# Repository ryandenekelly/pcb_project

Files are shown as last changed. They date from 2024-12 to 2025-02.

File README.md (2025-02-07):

# STM32 PCB Project
**Very much a work in progress**

PCB prototype project using KiCad and based on ST32F411RET7. 
The goal is to utilise the SSD1306 or ST7735 LCD displays and RFM69 radio to make a sensor sever / controller.

## Schematic
### MCU

Circuitry to power microcontroller and its nesessary parts.

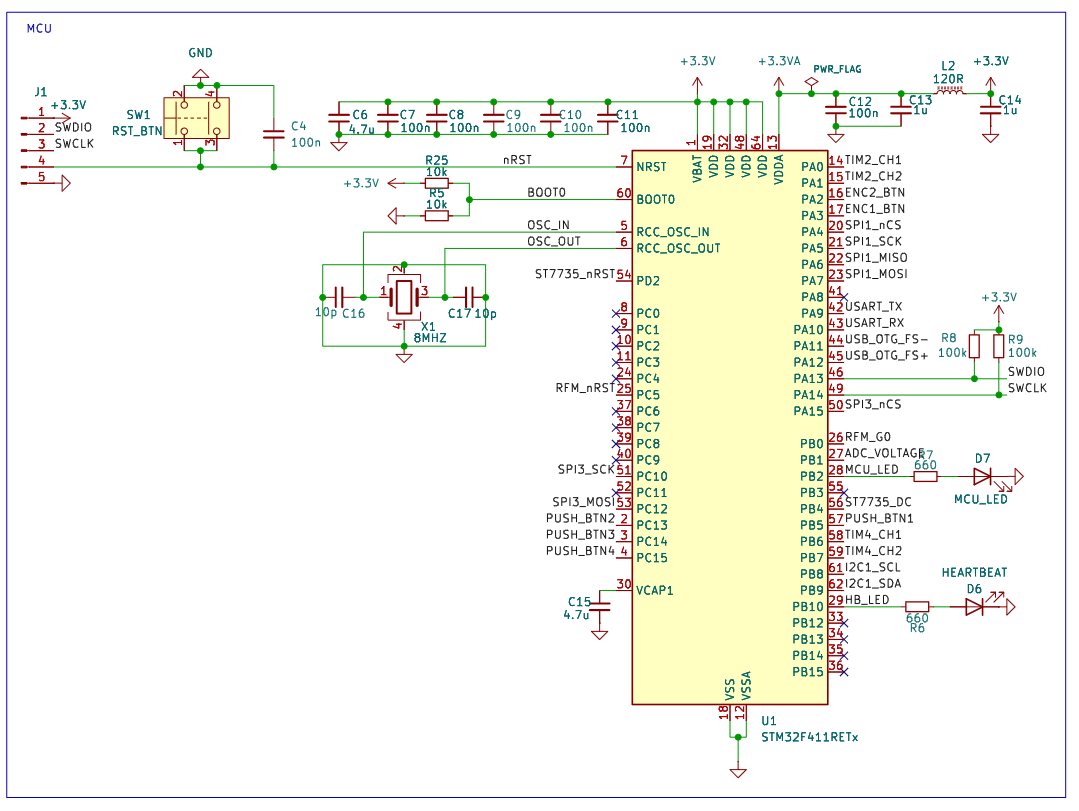
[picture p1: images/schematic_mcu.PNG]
MCU section of the schematic


### Power

USB-C/Battery power and regulator.

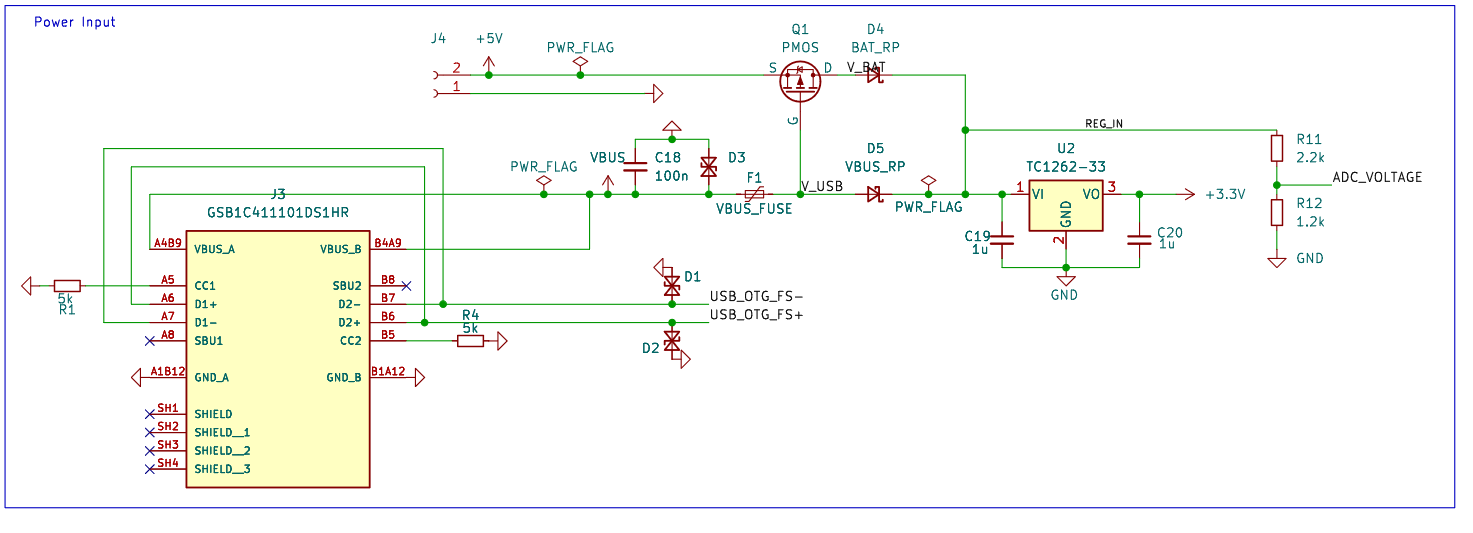
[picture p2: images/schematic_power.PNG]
Power section of the schematic

### UART
USB-B UART input.
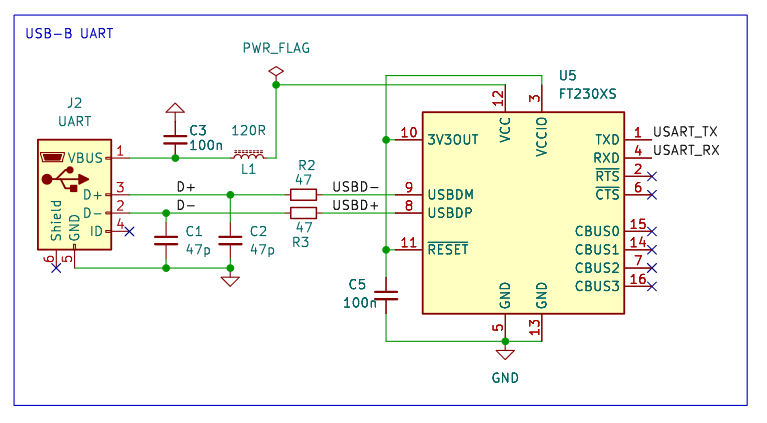
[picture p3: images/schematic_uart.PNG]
UART section of the schematic

### Radio and Display
Headers for RFM69 radio and LCD displays
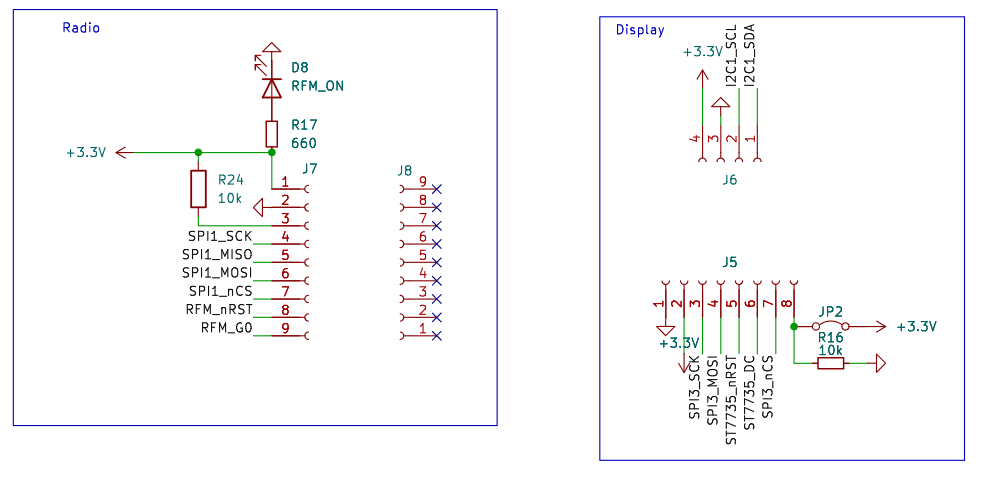
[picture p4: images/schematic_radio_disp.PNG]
Radio and display section of the schematic

### Input
Push button and encoder input with filtering.
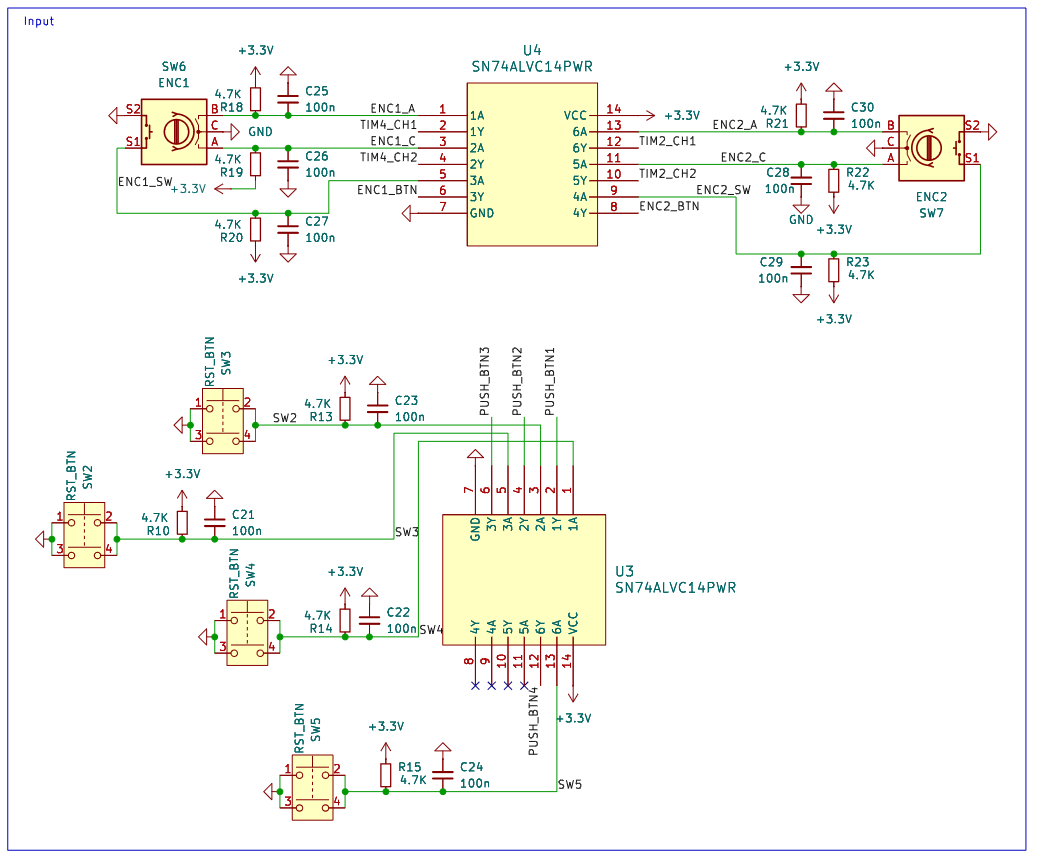
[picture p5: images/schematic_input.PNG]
Input section of the schematic


## PCB

First version of PCB

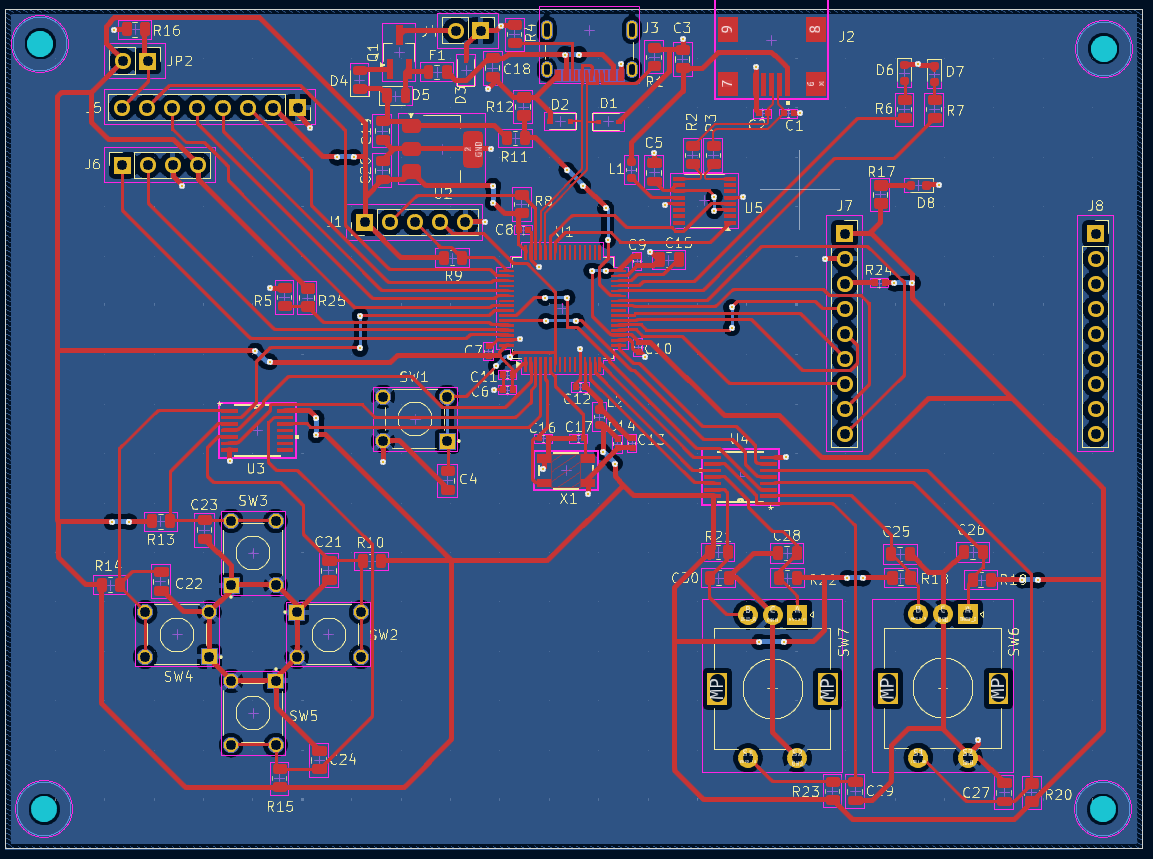
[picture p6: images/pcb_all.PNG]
Full PCB


### Top Layer

Top layer containing the signals and power.

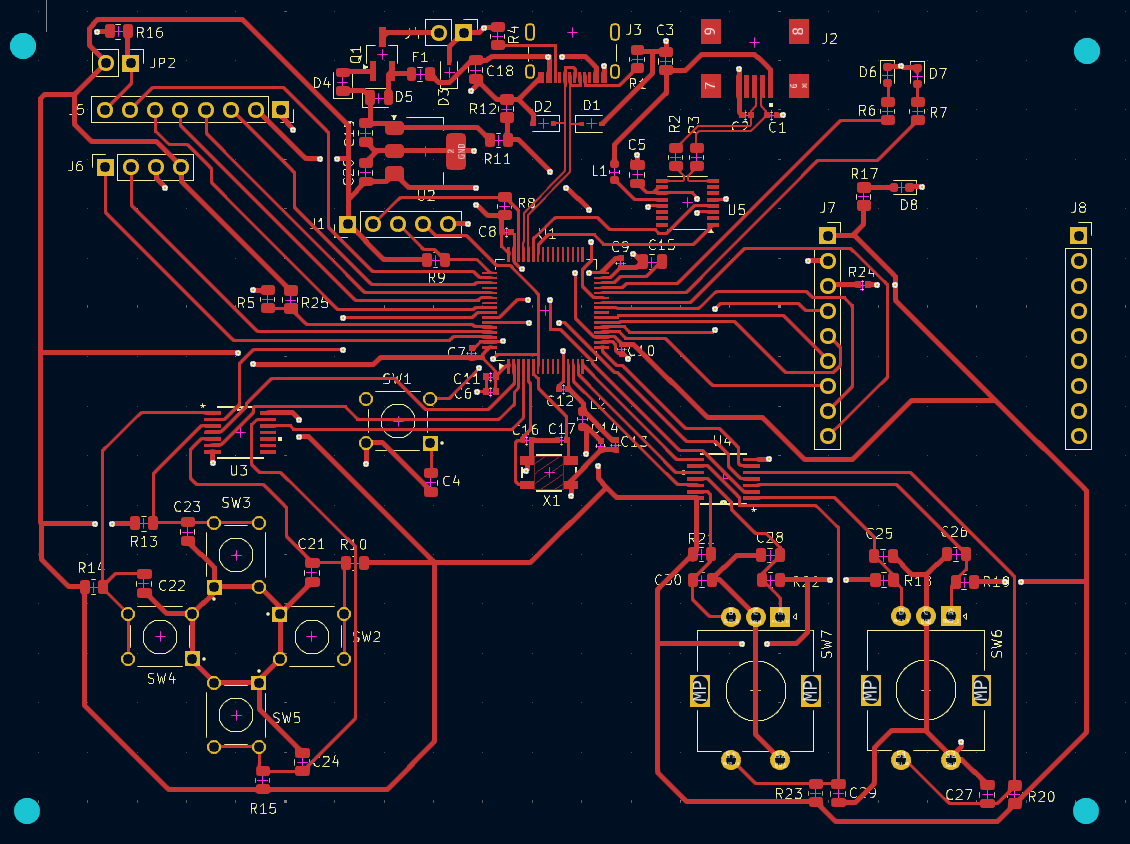
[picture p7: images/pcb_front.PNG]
Just the top layer of the PCB


### Bottom Layer

Bottom layer containing mostly the GND plane, with some signals from vias.

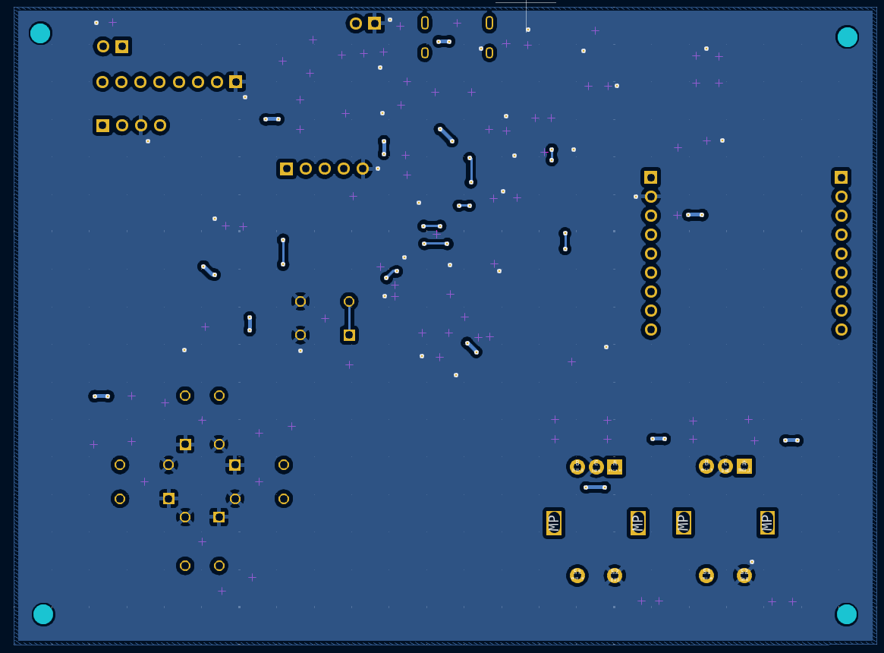
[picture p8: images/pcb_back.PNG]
Just the bottom layer of PCB


### Future Improvement

Currently in the proccess of assembling pcb. The wrong size capacitors were ordered for C13 and C14, but were assembled with some reworking.
May need re-design on crystal oscilator to use a part that is more easily hand soldered. Boot and reset nets may need reworking.

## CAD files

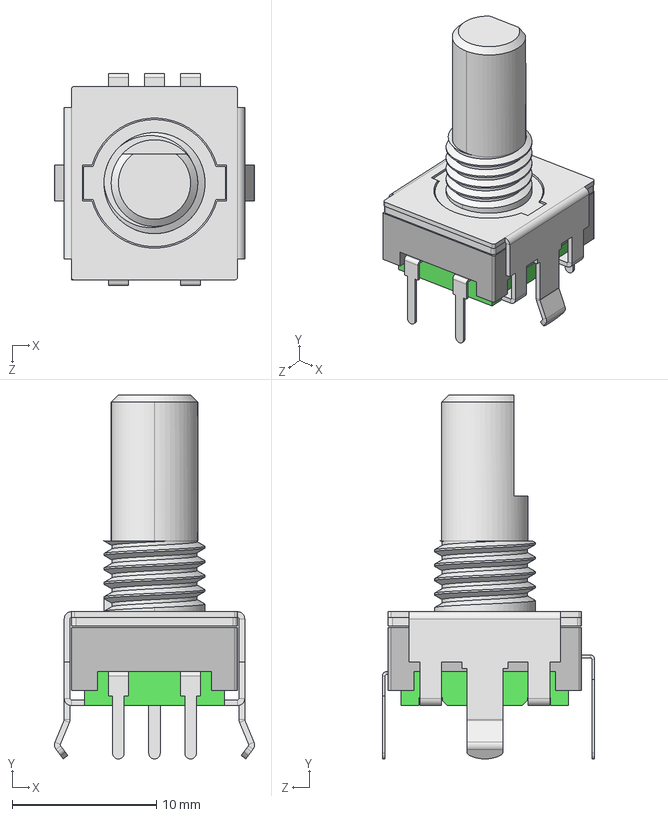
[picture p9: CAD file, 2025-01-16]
project_library/PEC11R-4215F-S0024.step
13.9 x 25.2 x 14.7 mm

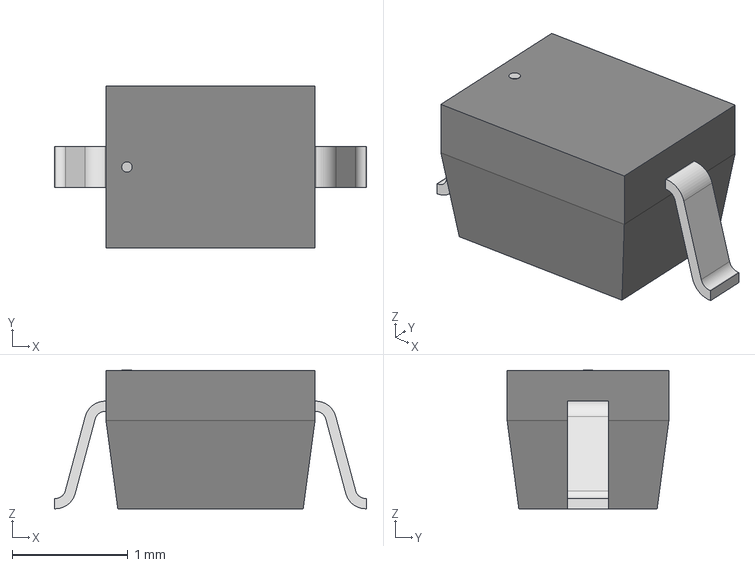
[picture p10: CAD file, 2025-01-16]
project_library/SOD323-L_DIO.step
2.69 x 1.40 x 1.20 mm

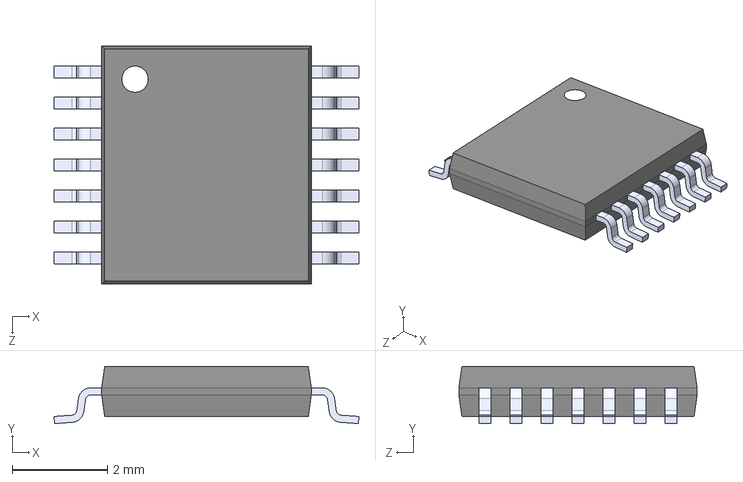
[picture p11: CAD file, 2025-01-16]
project_library/SN74ALVC14PWR.step
6.40 x 1.20 x 5.00 mm

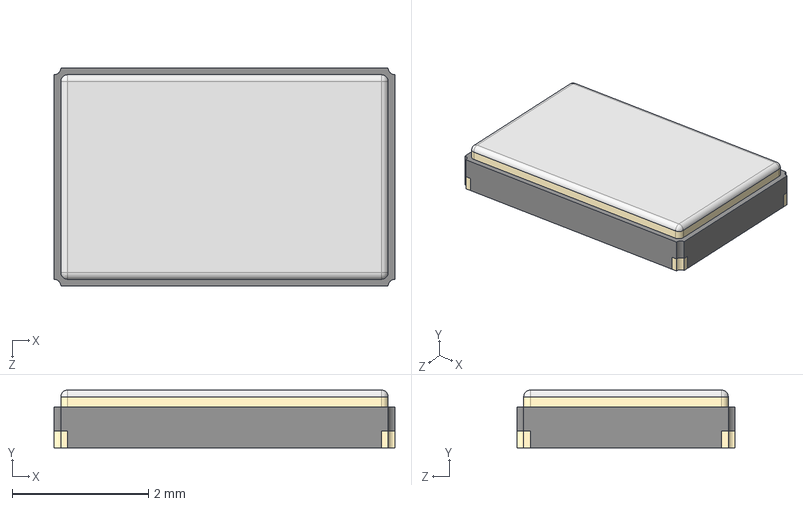
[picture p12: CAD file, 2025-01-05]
project_library/ECS-80-10-30B-CKM-TR.step
5.00 x 0.85 x 3.20 mm

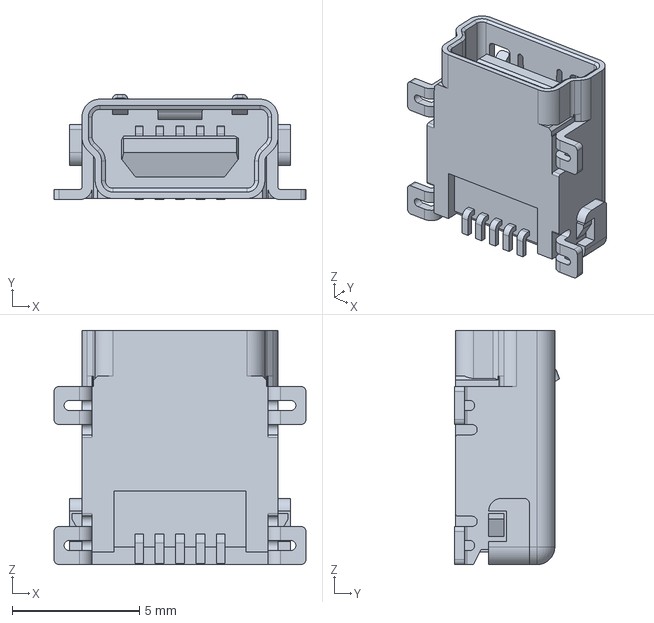
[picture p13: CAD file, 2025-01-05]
project_library/c-1-1734035-2-f-3d.stp
9.90 x 4.14 x 9.20 mm

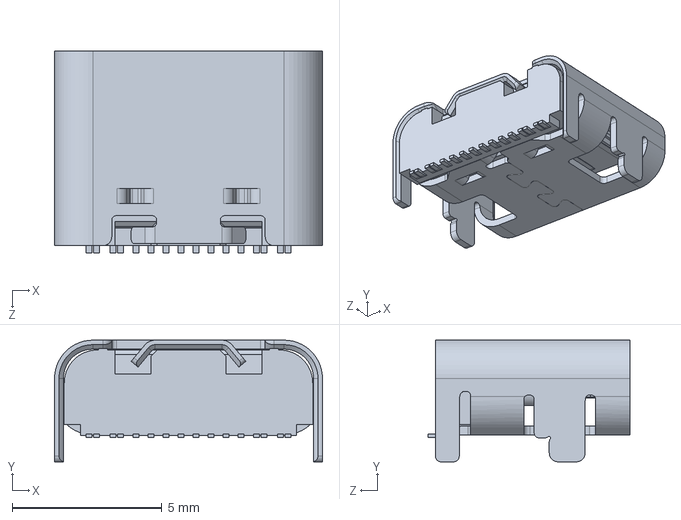
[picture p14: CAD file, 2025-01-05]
project_library/GSB1C411101DS1HR.step
8.94 x 4.06 x 6.75 mm

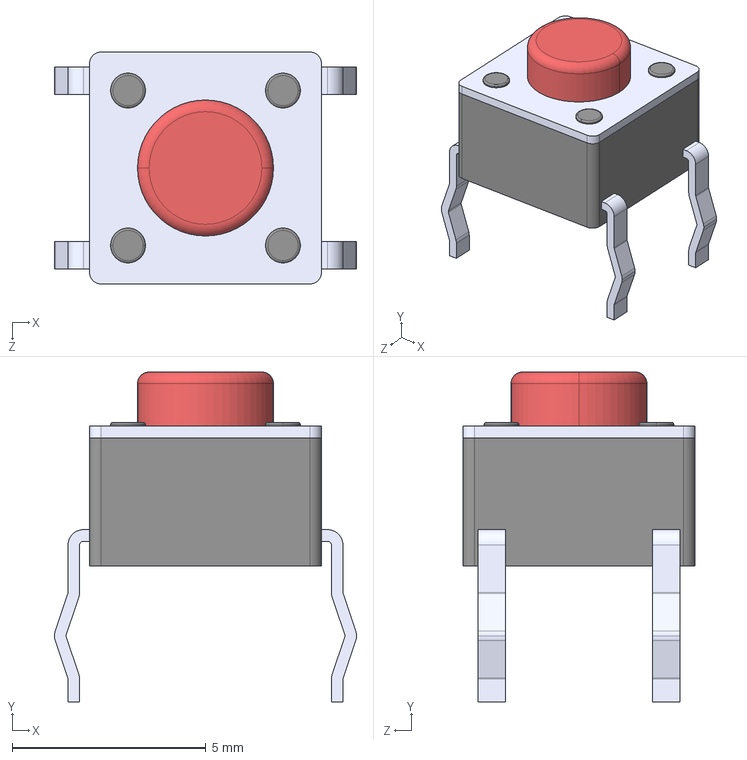
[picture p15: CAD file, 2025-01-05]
project_library/1825910-6.step
7.80 x 8.52 x 5.99 mm

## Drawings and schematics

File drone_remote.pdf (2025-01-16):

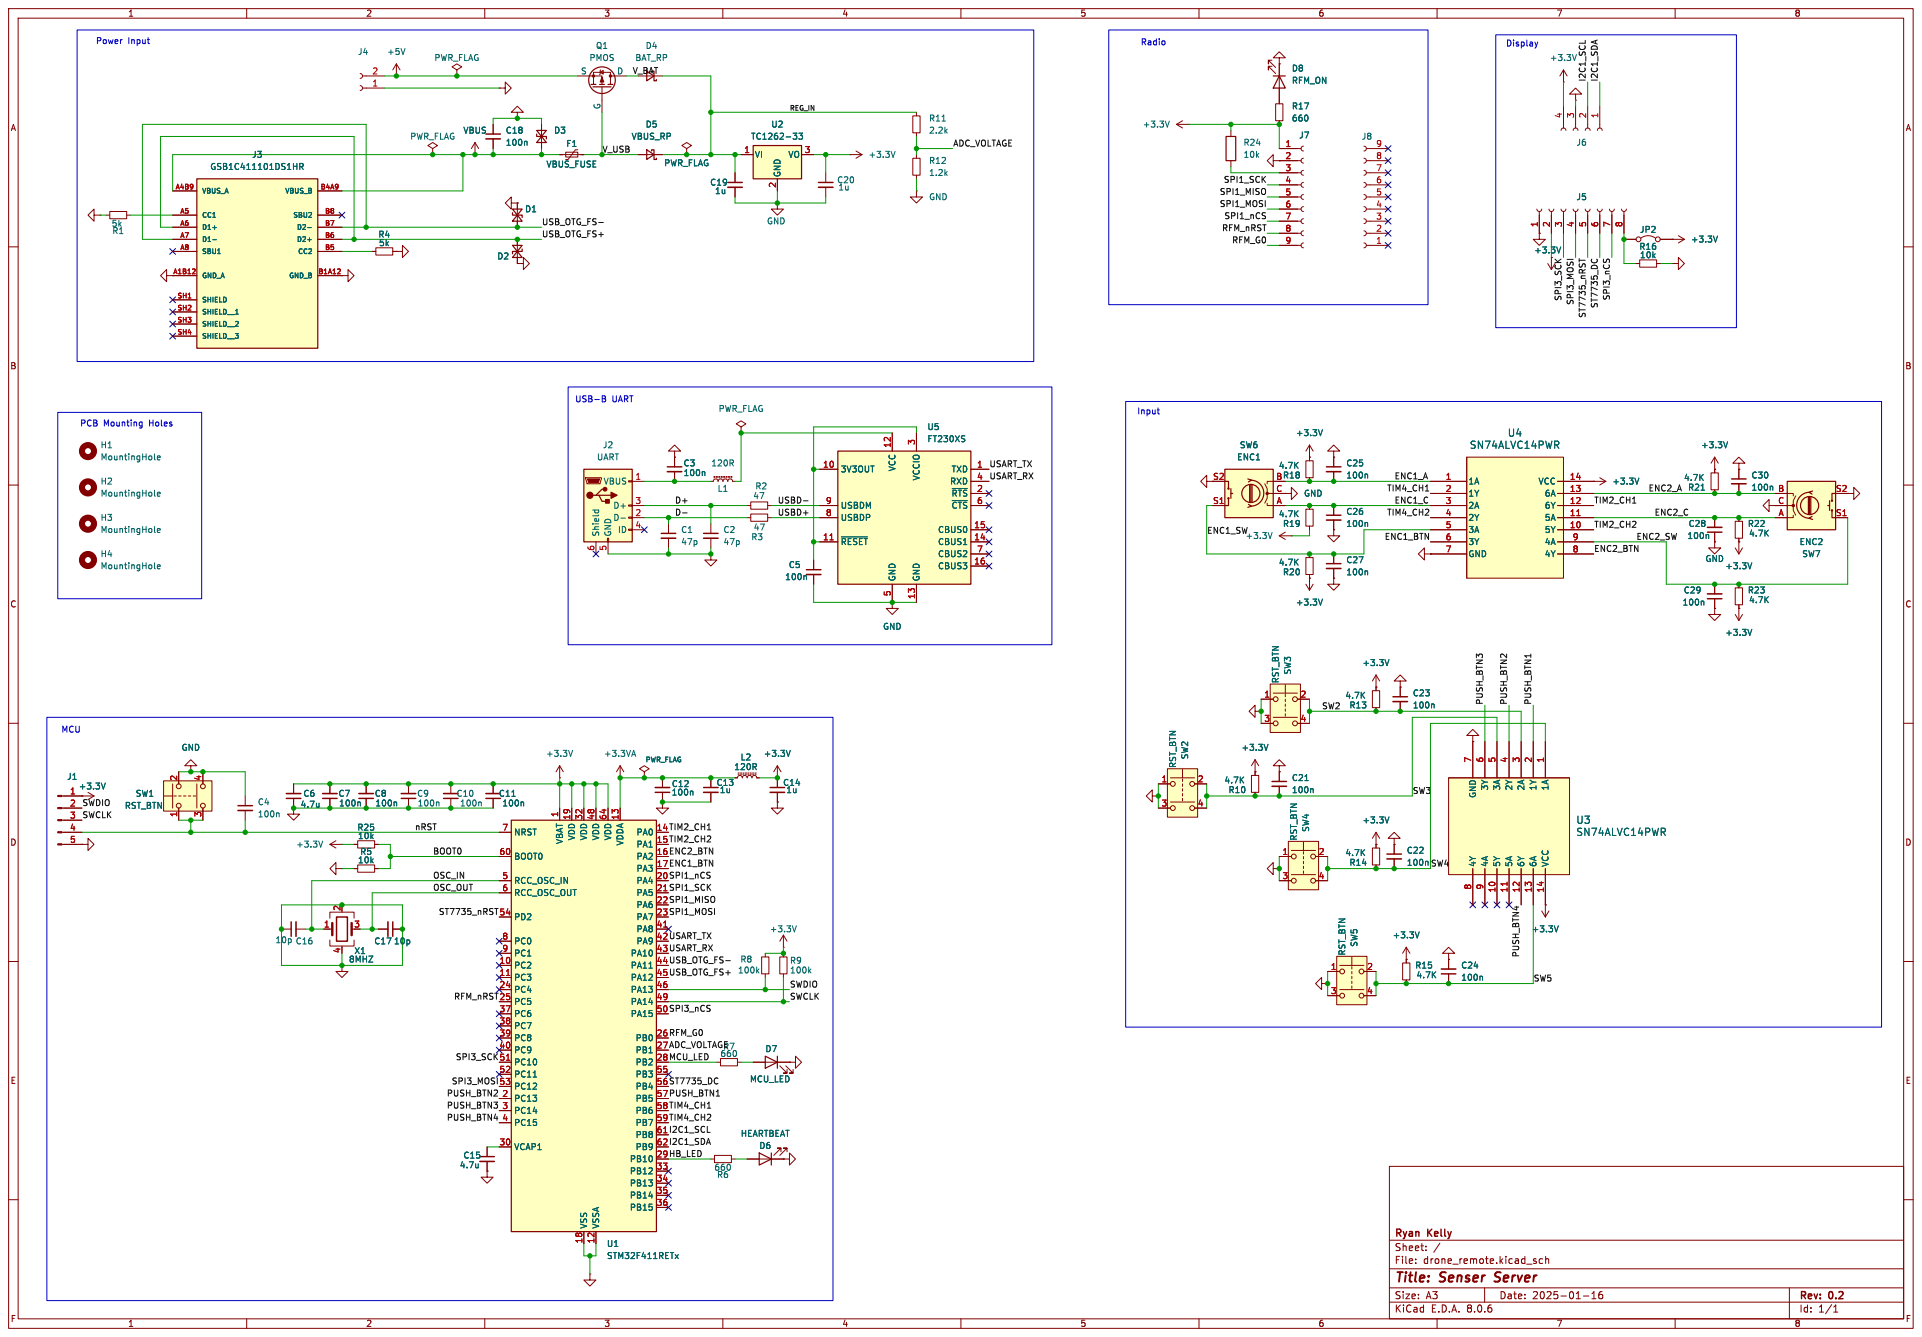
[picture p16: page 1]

5 ~{CTS}6 CBUS2 7 USBDP 8 USBDM 9 GND

1 PC2 10 PC3 11 VSSA 12 VDDA 13 PA0 14 PA1 15 PA2 16 PA3 17 VSS 18 VDD 19 PC13 2 PA4 20 PA5 21 PA6 22 PA7 23 PC4 24 PC5 25 PB0 26 PB1 27 PB2 28 PB10 29 PC14 3 VCAP1 30 VDD 32 PB12 33 PB13 34 PB14 35 PB15 36 PC6 37 PC7 38 PC8 39 PC15 4 PC9 40 PA8 41 PA9 42 PA10 43 PA11 44 PA12 45 PA13 46 VDD 48 PA14 49 RCC_OSC_IN 5 PA15 50 PC10 51 PC11 52 PC12 53 PD2 54 PB3 55 PB4 56 PB5 57 PB6 58 PB7 59 RCC_OSC_OUT 6 BOOT0 60 PB8 61 PB9 62 VDD 64 NRST 7 PC0 8 PC1 9 C15

1 PC2 10 PC3 11 VSSA 12 VDDA 13 PA0 14 PA1 15 PA2 16 PA3 17 VSS 18 VDD 19 PC13 2 PA4 20 PA5 21 PA6 22 PA7 23 PC4 24 PC5 25 PB0 26 PB1 27 PB2 28 PB10 29 PC14 3 VCAP1 30 VDD 32 PB12 33 PB13 34 PB14 35 PB15 36 PC6 37 PC7 38 PC8 39 PC15 4 PC9 40 PA8 41 PA9 42 PA10 43 PA11 44 PA12 45 PA13 46 VDD 48 PA14 49 RCC_OSC_IN 5 PA15 50 PC10 51 PC11 52 PC12 53 PD2 54 PB3 55 PB4 56 PB5 57 PB6 58 PB7 59 RCC_OSC_OUT 6 BOOT0 60 PB8 61 PB9 62 VDD 64 NRST 7 PC0 8 PC1 9 U1STM32F411RETx

Id: 1/1 Title: Senser Server File: drone_remote.kicad_sch Sheet: / Ryan Kelly

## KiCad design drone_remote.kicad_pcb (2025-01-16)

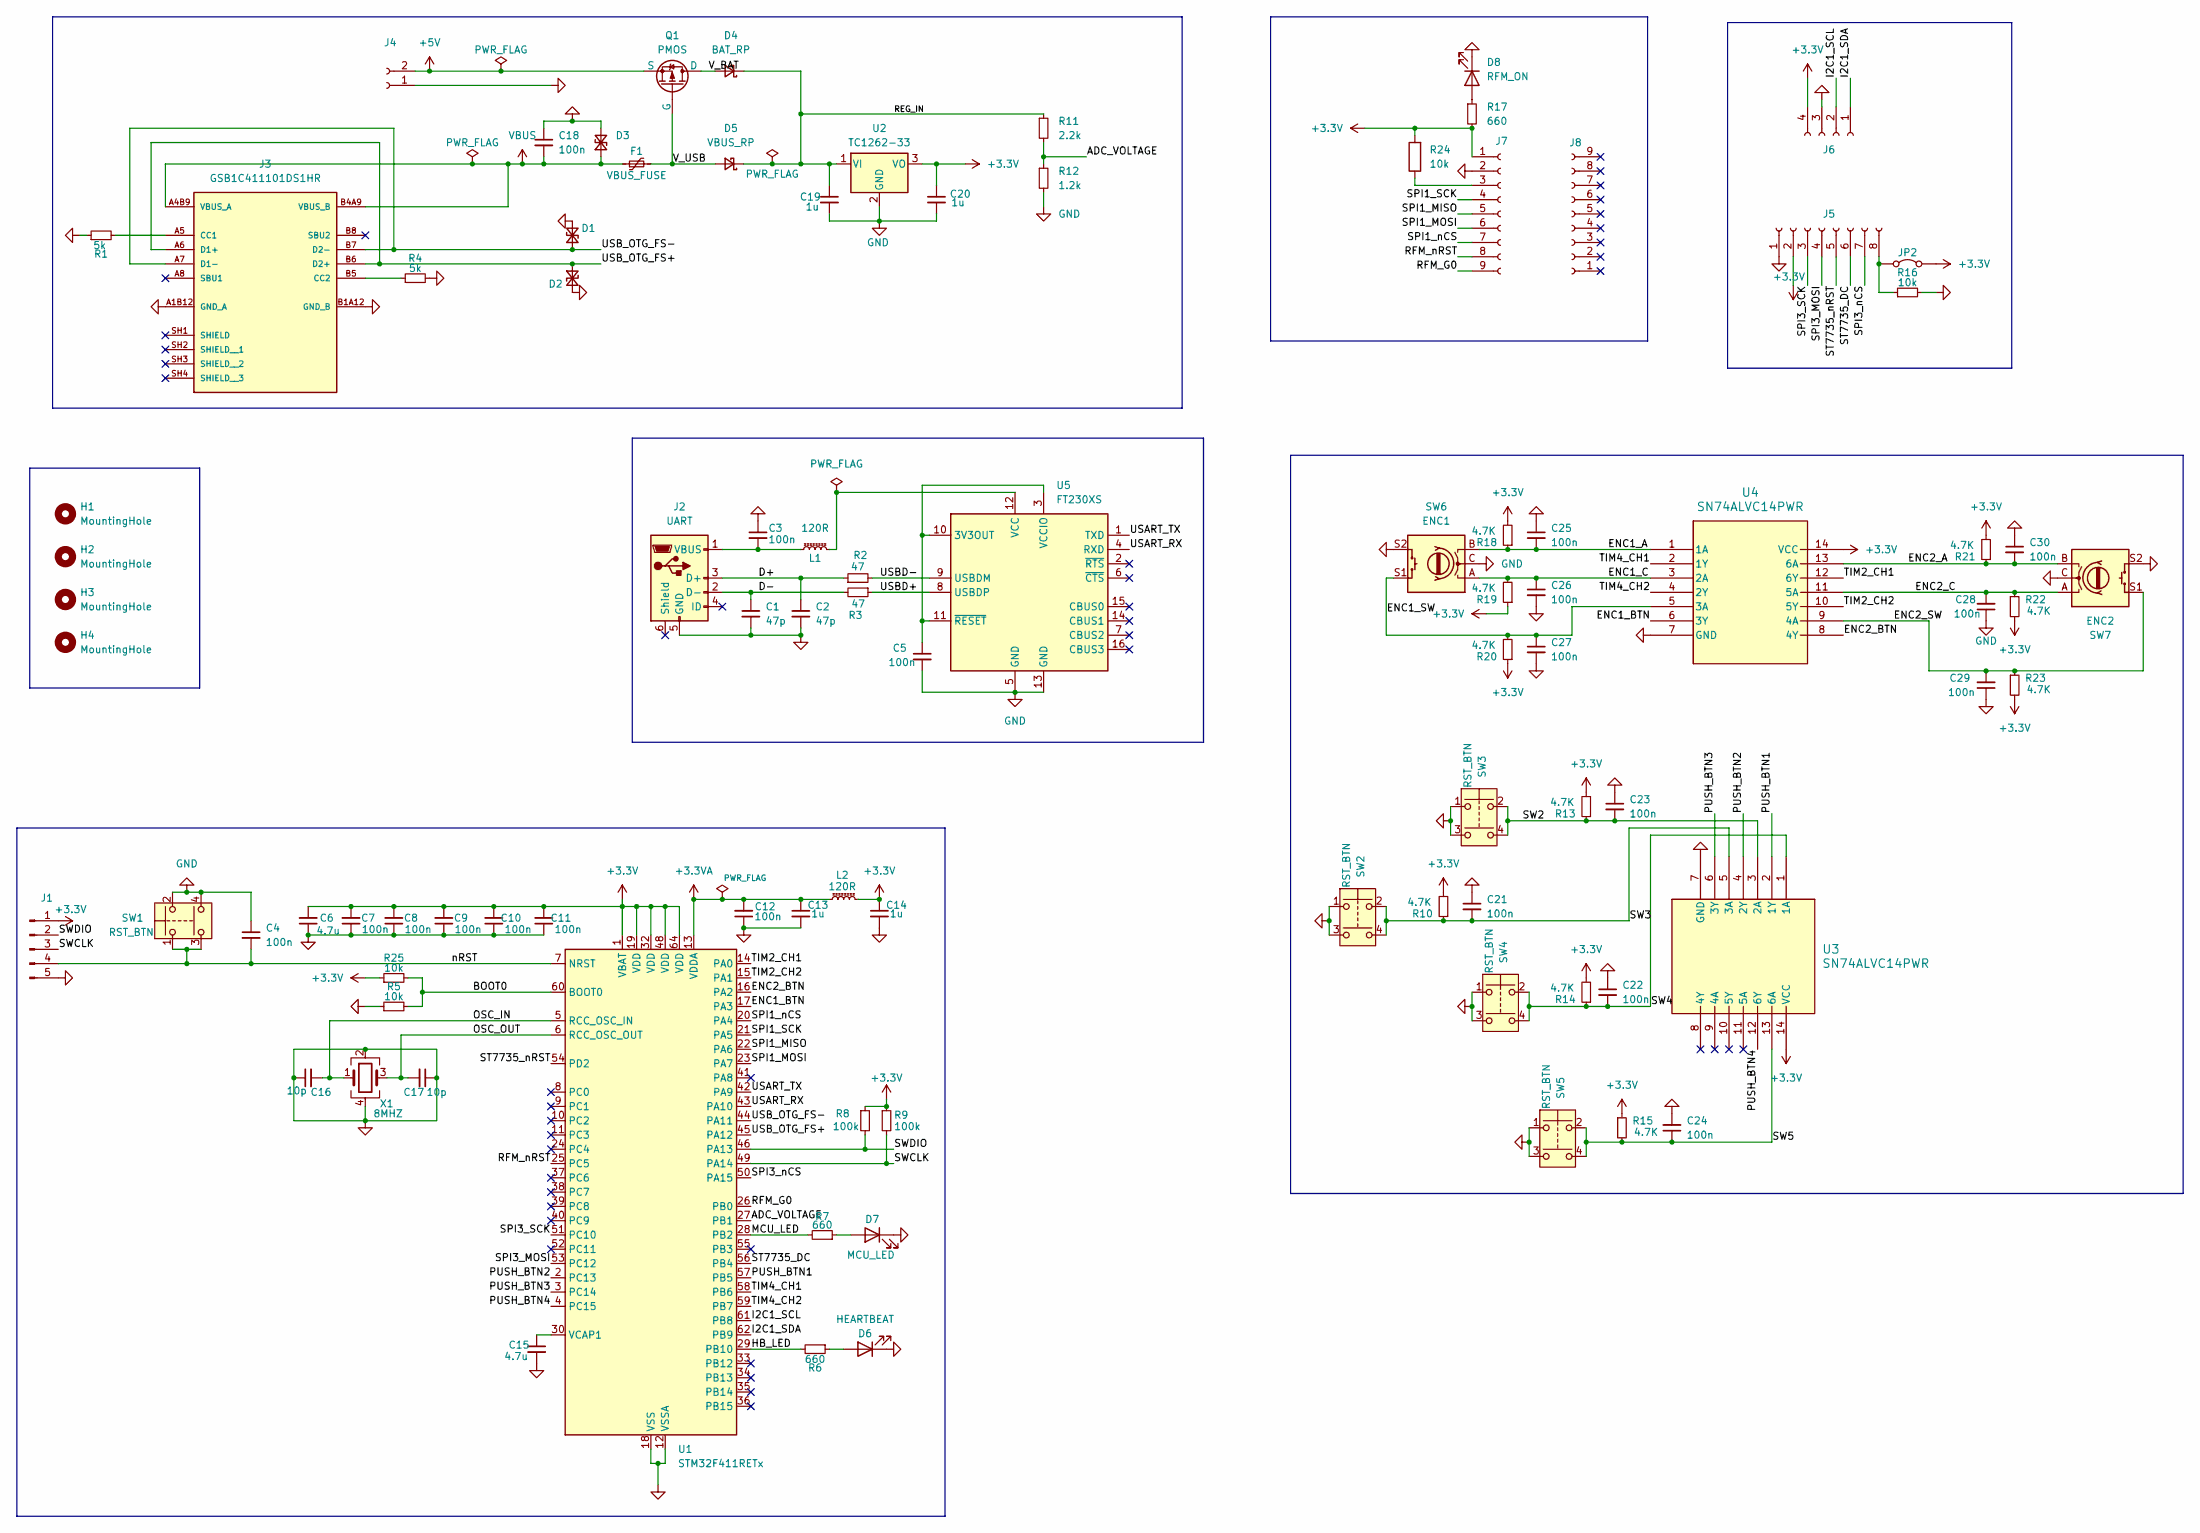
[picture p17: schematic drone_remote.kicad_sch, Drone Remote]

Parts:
C1, C2: 47p; C_0402_1005Metric
C3, C4, C5, C18, C21, C22, C23, C24, C25, C26, C27, C28, C29, C30: 100n; C_0805_2012Metric
C6: 4.7u; C_0402_1005Metric
C7, C8, C9, C10, C11, C12: 100n; C_0402_1005Metric
C13, C14: 1u; C_0402_1005Metric
C15: 4.7u; C_0805_2012Metric
C16, C17: 10p; C_0402_1005Metric
C19, C20: 1u; C_0805_2012Metric
D1: DN_TVS; D_SOD-323
D2: DP_TVS; D_SOD-323
D3: D_TVS_Small; D_SOD-323
D4: BAT_RP; D_0805_2012Metric
D5: VBUS_RP; D_0805_2012Metric
D6: HEARTBEAT; LED_0603_1608Metric
D7: MCU_LED; LED_0603_1608Metric
D8: RFM_ON; LED_0603_1608Metric
F1: VBUS_FUSE; Fuse_0805_2012Metric
H1, H2, H3, H4: MountingHole; MountingHole_2.7mm_M2.5
J1: Conn_01x05_Pin; PinHeader_1x05_P2.54mm_Vertical
J2: UART; CONN5_USB1734035_NP_TEC
J3: GSB1C411101DS1HR; AMPHENOL_GSB1C411101DS1HR; PARTREV AX3
J4: Conn_01x02_Socket; PinHeader_1x02_P2.54mm_Vertical
J5: Conn_01x08_Socket; PinSocket_1x08_P2.54mm_Vertical
J6: Conn_01x04_Socket; PinSocket_1x04_P2.54mm_Vertical
J7, J8: Conn_01x09_Socket; PinSocket_1x09_P2.54mm_Vertical
JP2: Jumper_2_Bridged; PinHeader_1x02_P2.54mm_Vertical
L1, L2: 120R; L_0603_1608Metric
Q1: PMOS; TSOT-23_HandSoldering
R1, R4: 5k; R_0805_2012Metric
R2, R3: 47; R_0805_2012Metric
R5, R16, R25: 10k; R_0805_2012Metric
R6, R7, R17: 660; R_0805_2012Metric
R8, R9: 100k; R_0805_2012Metric
R10, R13, R14, R15, R18, R19, R20, R21, R22, R23: 4.7K; R_0805_2012Metric
R11: 2.2k; R_0805_2012Metric
R12: 1.2k; R_0805_2012Metric
R24: 10k; R_0402_1005Metric
SW1, SW2, SW3, SW4, SW5: RST_BTN; SW_1825910-6-4
SW6: ENC1; RotaryEncoder_Alps_EC11E-Switch_Vertical_H20mm
SW7: ENC2; RotaryEncoder_Alps_EC11E-Switch_Vertical_H20mm
U1: STM32F411RETx; LQFP-64_10x10mm_P0.5mm
U2: TC1262-33; SOT-223-3_TabPin2
U3, U4: SN74ALVC14PWR; PW14
U5: FT230XS; SSOP-16_3.9x4.9mm_P0.635mm
X1: 8MHZ; SMD_ECS-80-10-3M-TR_ECS

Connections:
+3.3V: C6.2, C7.2, C8.2, C9.2, C10.2, C11.2, C14.1, C20.1, J1.1, J5.2, J6.4, J7.1, JP2.2 (B), L2.2, R8.1, R9.1, R10.2, R13.2, R14.2, R15.1, R17.2, R18.2, R19.1, R20.1, R21.2, R22.2, R23.2, R24.2, R25.1, U1.1 (VBAT), U1.19 (VDD), U1.32 (VDD), U1.48 (VDD), U1.64 (VDD), U2.3 (VO), U3.14 (VCC), U4.14 (VCC)
+3.3VA: C12.2, C13.1, L2.1, U1.13 (VDDA)
+5V: J4.2, Q1.3 (S)
/ADC_VOLTAGE: R11.2, R12.1, U1.27 (PB1)
/BOOT0: R5.2, R25.2, U1.60 (BOOT0)
/D+: C2.1, J2.3 (D+), R2.1
/D-: C1.1, J2.2 (D-), R3.2
/ENC1_A: C25.2, R18.1, SW6.B, U4.1 (1A)
/ENC1_BTN: U1.17 (PA3), U4.6 (3Y)
/ENC1_C: C26.1, R19.2, SW6.A, U4.3 (2A)
/ENC1_SW: C27.1, R20.2, SW6.S1, U4.5 (3A)
/ENC2_A: C30.2, R21.1, SW7.B, U4.13 (6A)
/ENC2_BTN: U1.16 (PA2), U4.8 (4Y)
/ENC2_C: C28.2, R22.1, SW7.A, U4.11 (5A)
/ENC2_SW: C29.2, R23.1, SW7.S1, U4.9 (4A)
/HB_LED: R6.2, U1.29 (PB10)
/I2C1_SCL: J6.2, U1.61 (PB8)
/I2C1_SDA: J6.1, U1.62 (PB9)
/MCU_LED: R7.2, U1.28 (PB2)
/OSC_IN: C16.2, U1.5 (RCC_OSC_IN), X1.1
/OSC_OUT: C17.2, U1.6 (RCC_OSC_OUT), X1.3
/PUSH_BTN1: U1.57 (PB5), U3.2 (1Y)
/PUSH_BTN2: U1.2 (PC13), U3.4 (2Y)
/PUSH_BTN3: U1.3 (PC14), U3.6 (3Y)
/PUSH_BTN4: U1.4 (PC15), U3.12 (6Y)
/REG_IN: C19.1, D4.1 (K), D5.1 (K), R11.1, U2.1 (VI)
/RFM_G0: J7.9, U1.26 (PB0)
/RFM_nRST: J7.8, U1.25 (PC5)
/SPI1_MISO: J7.5, U1.22 (PA6)
/SPI1_MOSI: J7.6, U1.23 (PA7)
/SPI1_SCK: J7.4, U1.21 (PA5)
/SPI1_nCS: J7.7, U1.20 (PA4)
/SPI3_MOSI: J5.4, U1.53 (PC12)
/SPI3_SCK: J5.3, U1.51 (PC10)
/SPI3_nCS: J5.7, U1.50 (PA15)
/ST7735_DC: J5.6, U1.56 (PB4)
/ST7735_nRST: J5.5, U1.54 (PD2)
/SW2: C23.2, R13.1, SW3.2, SW3.4, U3.3 (2A)
/SW3: C21.2, R10.1, SW2.2, SW2.4, U3.5 (3A)
/SW4: C22.2, R14.1, SW4.2, SW4.4, U3.1 (1A)
/SW5: C24.1, R15.2, SW5.2, SW5.4, U3.13 (6A)
/SWCLK: J1.3, R9.2, U1.49 (PA14)
/SWDIO: J1.2, R8.2, U1.46 (PA13)
/TIM2_CH1: U1.14 (PA0), U4.12 (6Y)
/TIM2_CH2: U1.15 (PA1), U4.10 (5Y)
/TIM4_CH1: U1.58 (PB6), U4.2 (1Y)
/TIM4_CH2: U1.59 (PB7), U4.4 (2Y)
/USART_RX: U1.43 (PA10), U5.4 (RXD)
/USART_TX: U1.42 (PA9), U5.1 (TXD)
/USBD+: R3.1, U5.8 (USBDP)
/USBD-: R2.2, U5.9 (USBDM)
/USB_OTG_FS+: D2.1 (A1), J3.A6 (D1+), J3.B6 (D2+), U1.45 (PA12)
/USB_OTG_FS-: D1.1 (A1), J3.A7 (D1-), J3.B7 (D2-), U1.44 (PA11)
/V_BAT: D4.2 (A), Q1.1 (D)
/V_USB: D5.2 (A), F1.2, Q1.2 (G)
/nRST: C4.2, J1.4, SW1.1, SW1.3, U1.7 (NRST)
GND: C1.2, C2.2, C3.1, C4.1, C5.2, C6.1, C7.1, C8.1, C9.1, C10.1, C11.1, C12.1, C13.2, C14.2, C15.2, C16.1, C17.1, C18.1, C19.2, C20.2, C21.1, C22.1, C23.1, C24.2, C25.1, C26.2, C27.2, C28.1, C29.1, C30.1, D1.2 (A2), D2.2 (A2), D3.2 (A2), D6.1 (K), D7.1 (K), D8.1 (K), J1.5, J2.5 (GND), J3.A1B12 (GND_A), J3.B1A12 (GND_B), J4.1, J5.1, J6.3, J7.2, R1.1, R4.2, R5.1, R12.2, R16.2, SW1.2, SW1.4, SW2.1, SW2.3, SW3.1, SW3.3, SW4.1, SW4.3, SW5.1, SW5.3, SW6.C, SW6.S2, SW7.C, SW7.S2, U1.12 (VSSA), U1.18 (VSS), U1.31 (VSS), U1.47 (VSS), U1.63 (VSS), U2.2 (GND), U3.7 (GND), U4.7 (GND), U5.5 (GND), U5.13 (GND), X1.2, X1.4
unnamed: D6.2 (A), R6.1
unnamed: D7.2 (A), R7.1
unnamed: D8.2 (A), R17.1
unnamed: C3.2, J2.1 (VBUS), L1.1
unnamed: J3.A5 (CC1), R1.2
unnamed: J3.B5 (CC2), R4.1
unnamed: J5.8, JP2.1 (A), R16.1
unnamed: J7.3, R24.1
unnamed: C15.1, U1.30 (VCAP1)
unnamed: C5.1, U5.3 (VCCIO), U5.10 (3V3OUT), U5.11 (~RESET)
unnamed: L1.2, U5.12 (VCC)
VBUS: C18.2, D3.1 (A1), F1.1, J3.A4B9 (VBUS_A), J3.B4A9 (VBUS_B)

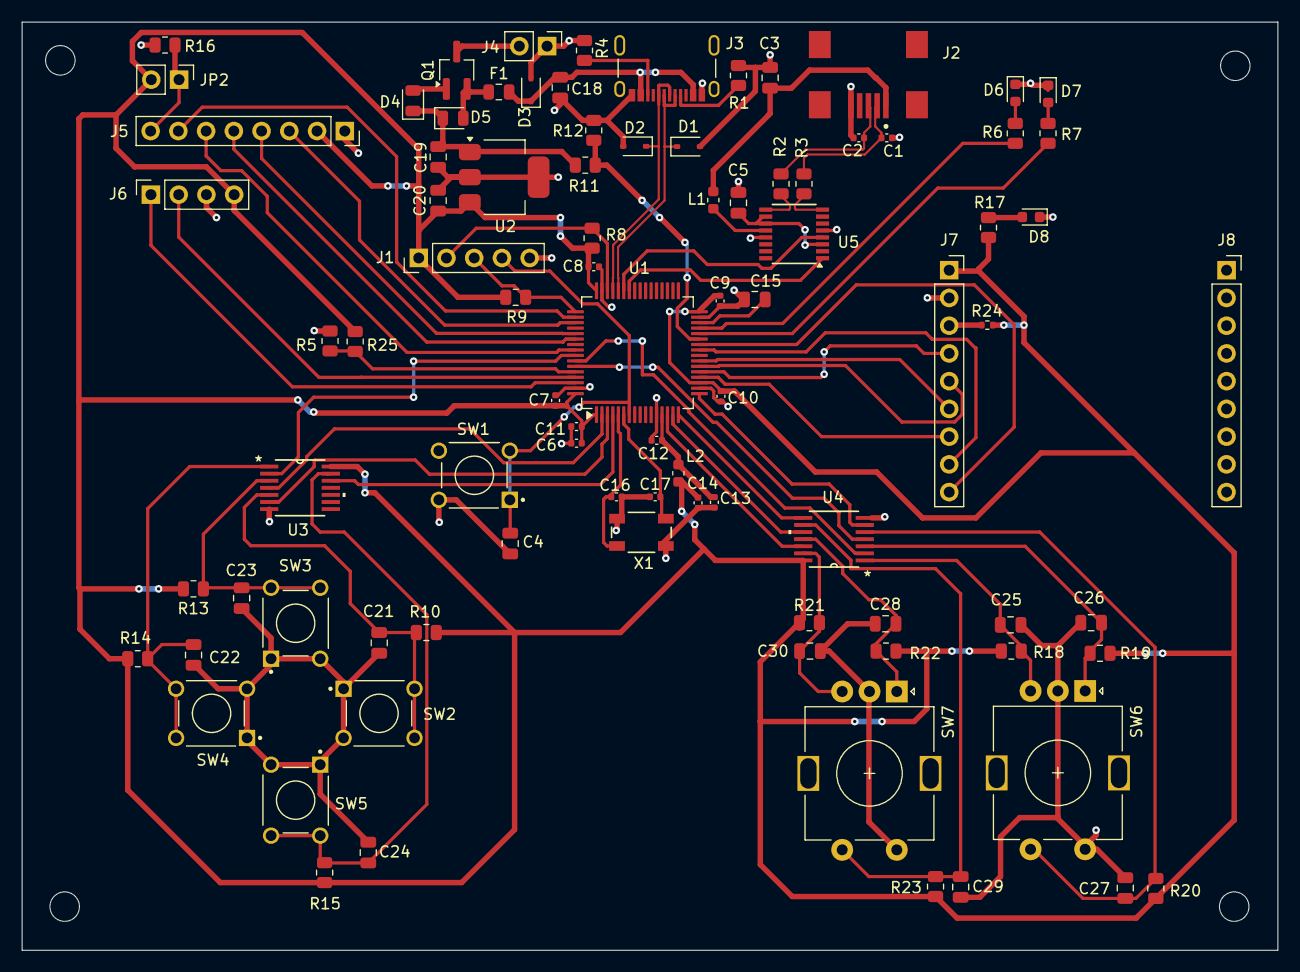
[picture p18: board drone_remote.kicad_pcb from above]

Board: 2 copper layers, 115.0 x 85.0 mm, 93 parts (0 on the bottom side), 69 nets.

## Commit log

2025-01-16 finalised first version of pcb, generated manufacturing files, cleaned up file dir
    [1825910-6.step, 690-005-299-043.step, ECS-80-10-30B-CKM-TR.step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]
2025-01-16 some images
    [drone_remote.kicad_sch]
2025-02-07 Update README.md about assembly progress
